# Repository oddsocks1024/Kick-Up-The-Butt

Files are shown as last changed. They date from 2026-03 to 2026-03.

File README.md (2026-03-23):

# Kick-Up-The-Butt - C64 / VIC20 Reset Cartridge

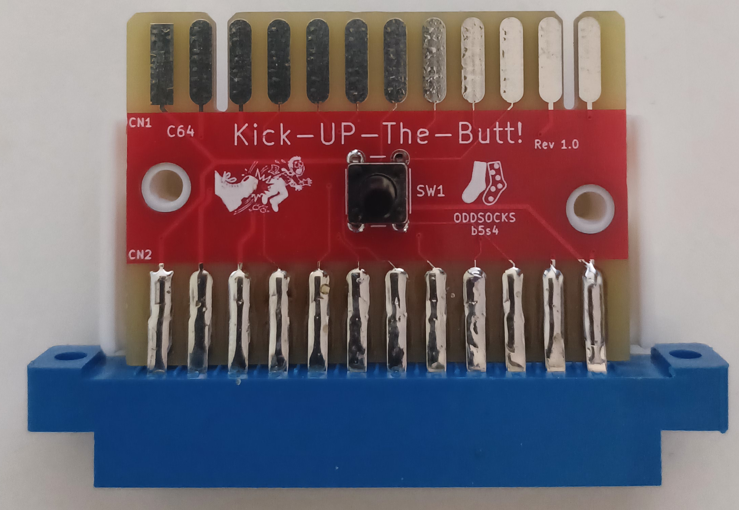
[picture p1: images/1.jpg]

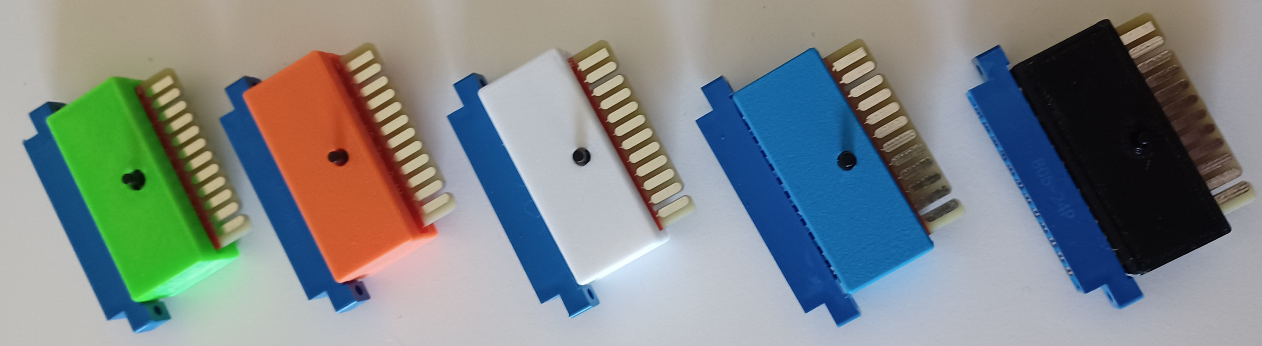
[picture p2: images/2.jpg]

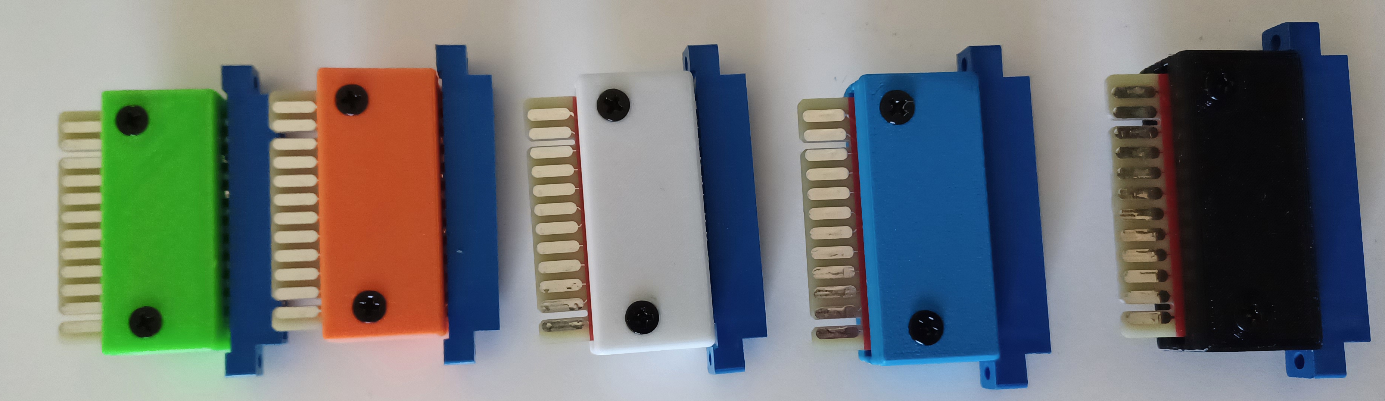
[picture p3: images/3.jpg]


## Description
A C64 / VIC20 reset cartridge with pass-through and a 3D printable case. Kick-Up-The-Butt! plugs into the user port and provides a simple reset button

## Bill of Materials

| Qty | Component |
|:---:|---|
| 1 | 6x6mm Tactile Button - ideally tall (or use optional reset pin) |
| 1 | 805-24P Connector - 24pin for C64 / VIC20 User Port |

* Ideally a tall tactile button should be used, but if you only have short ones you can 3D print the STL reset pin and use that to extend it.
* When attaching the 805-24P connector, gently bend the pins with pliers so they touch the pads on both sides. Make sure the PCB is straight before soldering.

## 3D Printable Case
A 3D printable case has been specifcally designed for this PCB and the STLs are included in the repo.

* Insert the PCB into the bottom case part, aligning the holes in the PCB with screw posts.
* Align the top part of the case with the bottom. (If using a reset pin, insert it before aligning).
* Screw together using 2 x 3.5mm self-tapping screws. Maximum length about 15mm.

---

## Support Me
Everything is freely available so you can make your own PCB and case, however if you would like to support me, please see the following links. 

* [My Projects](https://projects.amiga-hardware.com) - Donate on this page
* [Order the Kick-Up-The-Butt PCB](https://www.pcbway.com/project/shareproject/Kick_Up_The_Butt_User_Port_Reset_Cart_for_C64_VIC_20_fc886e20.html)
* [Order the Kick-Up-The-Butt Case](https://www.pcbway.com/project/shareproject/Kick_Up_The_Butt_User_Port_Reset_Cart_for_C64_VIC_20_Case_bae8bbd3.html)

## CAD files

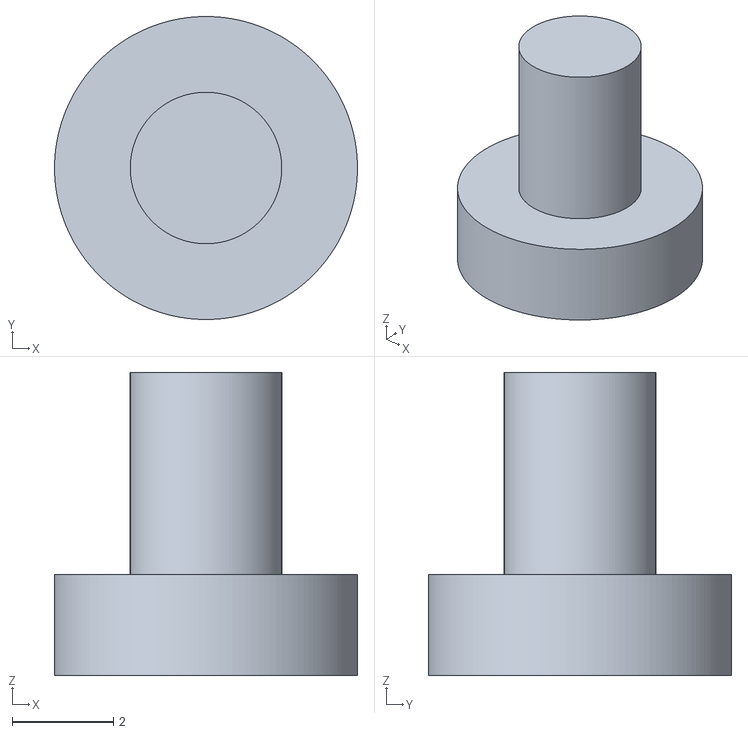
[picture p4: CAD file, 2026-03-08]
STL/Reset-Pin-Optional.stl
6.00 x 6.00 x 6.00

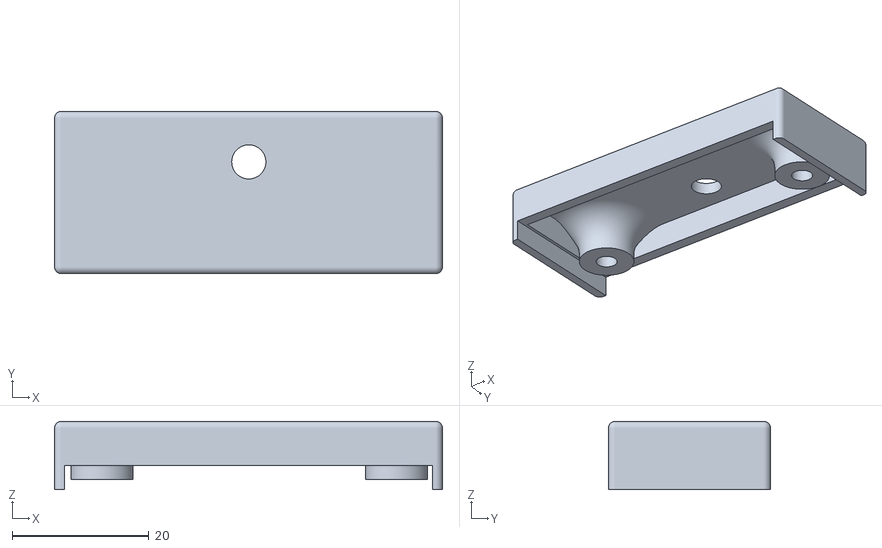
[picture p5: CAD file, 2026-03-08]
STL/Kick-UP-The-Butt - Case - Top.stl
56.8 x 23.8 x 10.0

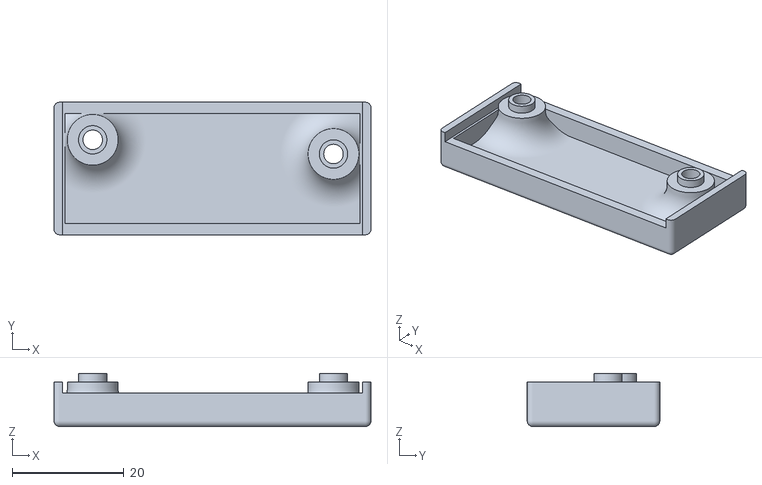
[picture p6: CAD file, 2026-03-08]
STL/Kick-UP-The-Butt - Case - Bottom.stl
56.8 x 23.8 x 9.51

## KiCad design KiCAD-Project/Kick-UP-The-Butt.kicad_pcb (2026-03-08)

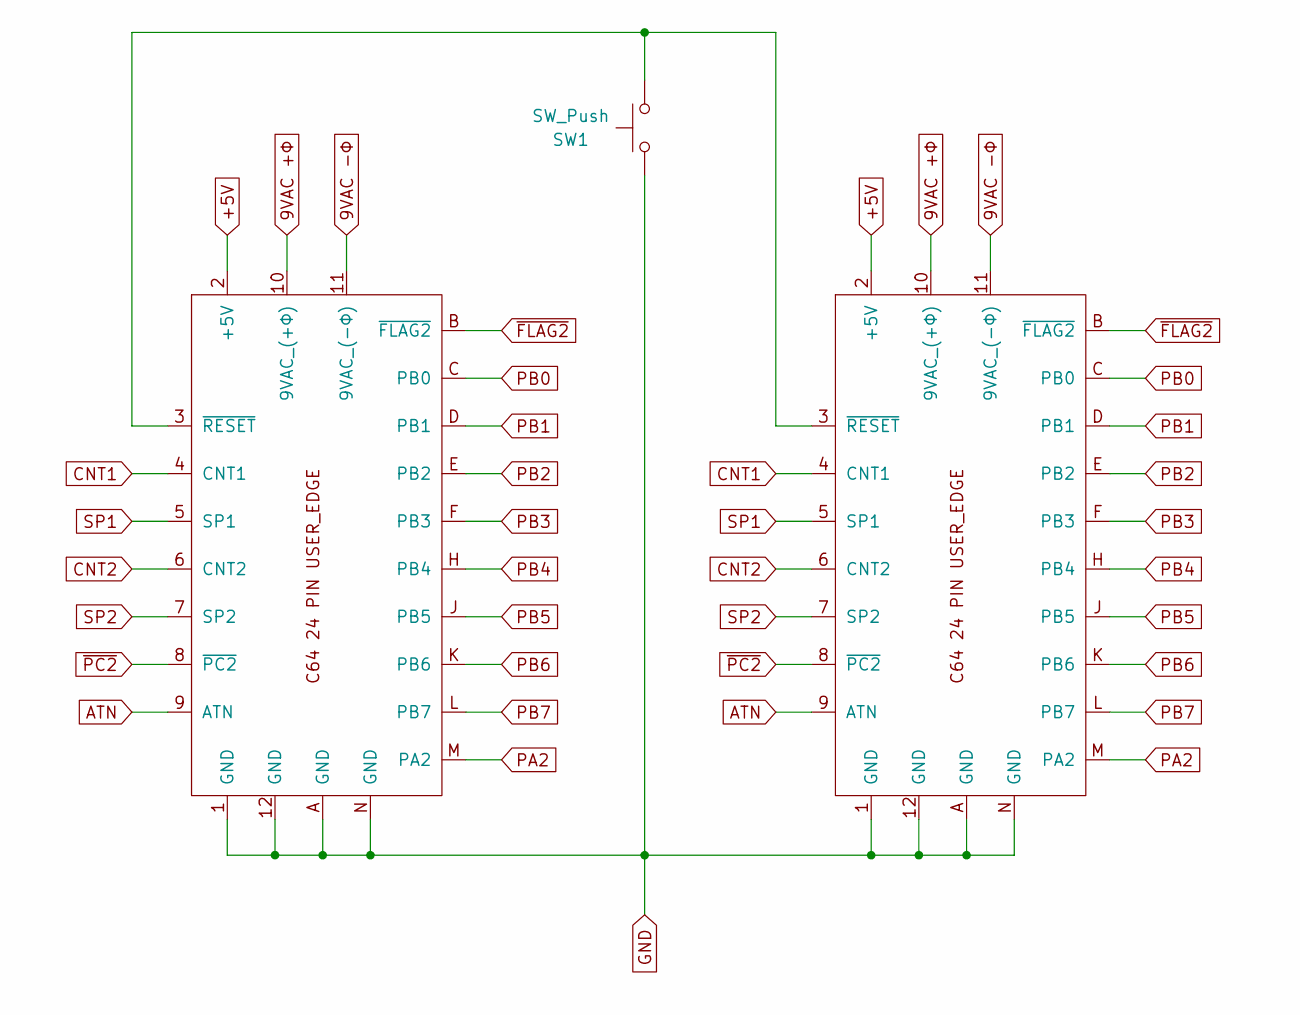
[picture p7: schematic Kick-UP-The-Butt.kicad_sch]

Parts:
CN1: C64 User Port Connector; C64 User Edge
CN2: C64 User Port Connector; C64 User Pads
SW1: SW_Push; SW_PUSH_6mm

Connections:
9VAC +Φ: CN1.10 (9VAC_(+Φ)), CN2.10 (9VAC_(+Φ))
9VAC -Φ: CN1.11 (9VAC_(-Φ)), CN2.11 (9VAC_(-Φ))
+5V: CN1.2 (+5V), CN2.2 (+5V)
ATN: CN1.9 (ATN), CN2.9 (ATN)
CNT1: CN1.4 (CNT1), CN2.4 (CNT1)
CNT2: CN1.6 (CNT2), CN2.6 (CNT2)
GND: CN1.1 (GND), CN1.12 (GND), CN1.A (GND), CN1.N (GND), CN2.1 (GND), CN2.12 (GND), CN2.A (GND), CN2.N (GND), SW1.1
unnamed: CN1.3 (~RESET), CN2.3 (~RESET), SW1.2
PA2: CN1.M (PA2), CN2.M (PA2)
PB0: CN1.C (PB0), CN2.C (PB0)
PB1: CN1.D (PB1), CN2.D (PB1)
PB2: CN1.E (PB2), CN2.E (PB2)
PB3: CN1.F (PB3), CN2.F (PB3)
PB4: CN1.H (PB4), CN2.H (PB4)
PB5: CN1.J (PB5), CN2.J (PB5)
PB6: CN1.K (PB6), CN2.K (PB6)
PB7: CN1.L (PB7), CN2.L (PB7)
SP1: CN1.5 (SP1), CN2.5 (SP1)
SP2: CN1.7 (SP2), CN2.7 (SP2)
~FLAG2: CN1.B (~FLAG2), CN2.B (~FLAG2)
~PC2: CN1.8 (~PC2), CN2.8 (~PC2)

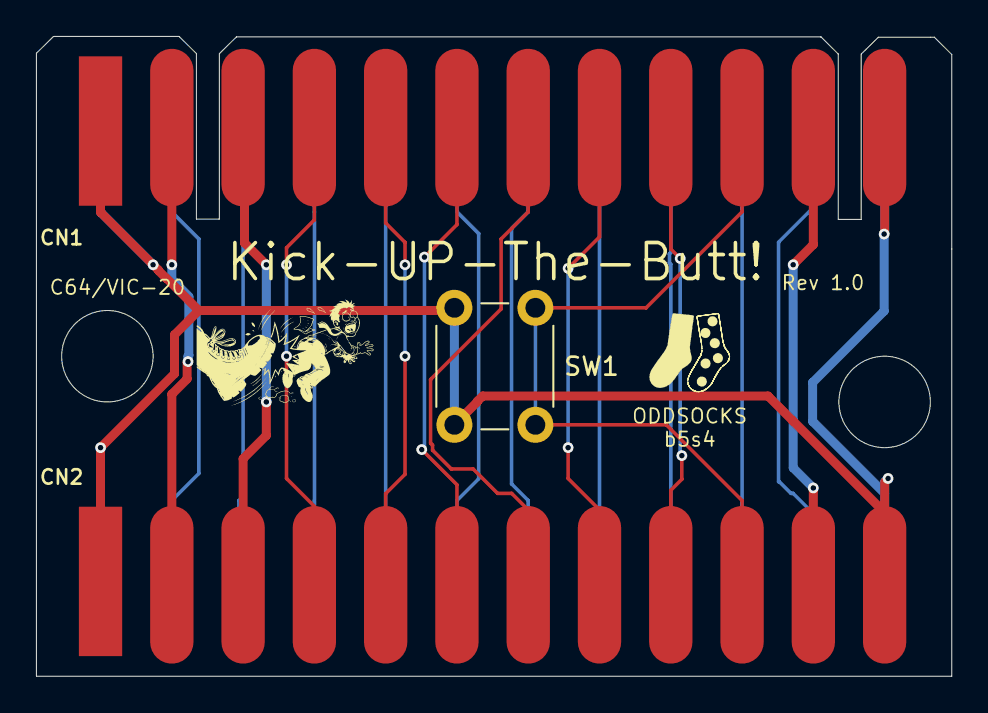
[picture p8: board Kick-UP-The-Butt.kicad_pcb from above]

Board: 2 copper layers, 50.8 x 35.5 mm, 3 parts (0 on the bottom side), 21 nets.
